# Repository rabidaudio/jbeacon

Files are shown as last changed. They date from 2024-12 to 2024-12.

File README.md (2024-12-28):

# JBeacon

Bluetooth beacons and Android app to stop forgetting your friggin keys.

- [Android App](/app)
- [PCB](/jbeacon)
- [Case model](https://cad.onshape.com/documents/ece1ed75d93c6672117b46a9/w/23cbe3629f57f254decfda38/e/c40ef07a7db79b811c868a6b)

## Licenses

Source Code is [MIT](LICENSE).

Hardware designs are [CC By 4.0](https://creativecommons.org/licenses/by/4.0/)

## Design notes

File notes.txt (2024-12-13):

MVP:
Show device - in range? approx distance?
Send notif when not in range
Send notif if bt disabled

optimize battery life

strech - app:
multiple devices
track location, record last known location
send notif when battery low

strech - hw:
buzzer: buzz when disconnected
buzz when commanded
acel/gyro motion detection to reduce advertising

https://cdn.sparkfun.com/assets/3/d/5/5/1/IN100-Datasheet.pdf

https://learn.sparkfun.com/tutorials/sparkfun-nanobeacon-board---in100-hookup-guide

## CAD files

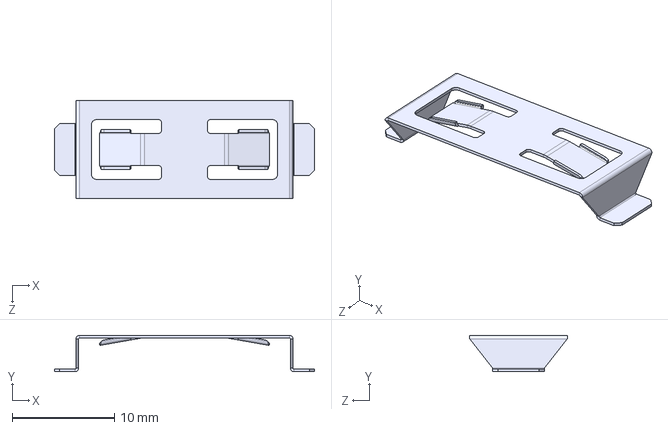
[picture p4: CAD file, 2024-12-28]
jbeacon/BC_2003_TR/BC-2003.step
25.4 x 3.56 x 9.53 mm

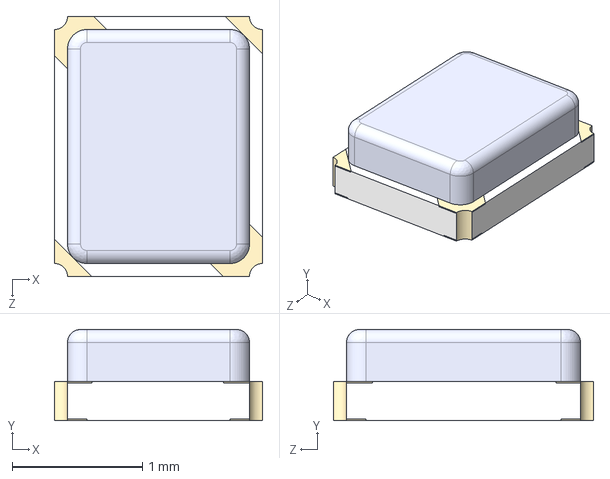
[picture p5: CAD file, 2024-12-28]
jbeacon/XRCGB26M000F2P00R0/XRCGB26M000F2P00R0.step
1.60 x 0.7 x 2.00 mm

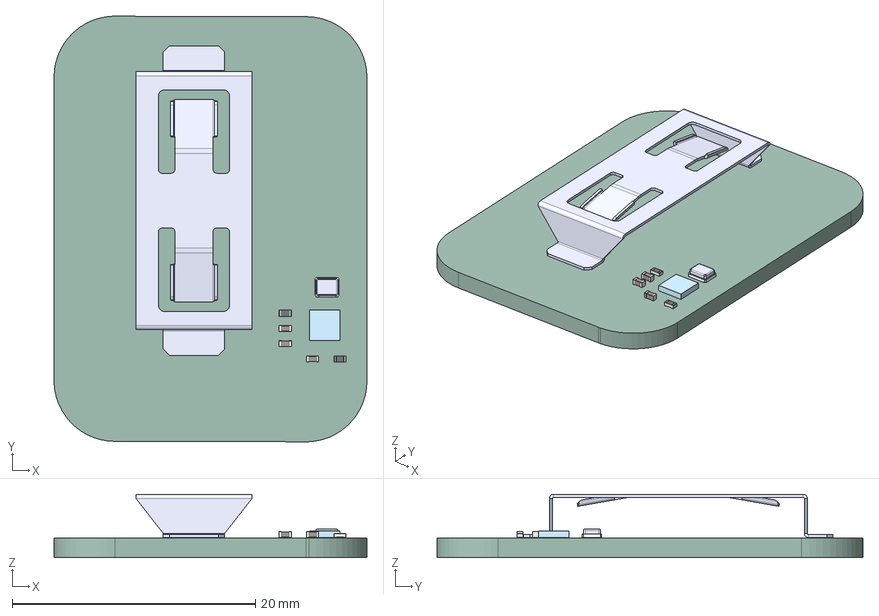
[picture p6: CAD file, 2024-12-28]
jbeacon/jbeacon.step
25.7 x 35.0 x 5.21 mm
C_0402_1005Metric x 3
XRCGB27M000F2P00R0
BC-2003
R_0402_1005Metric x 2
QFN8
jbeacon_PCB

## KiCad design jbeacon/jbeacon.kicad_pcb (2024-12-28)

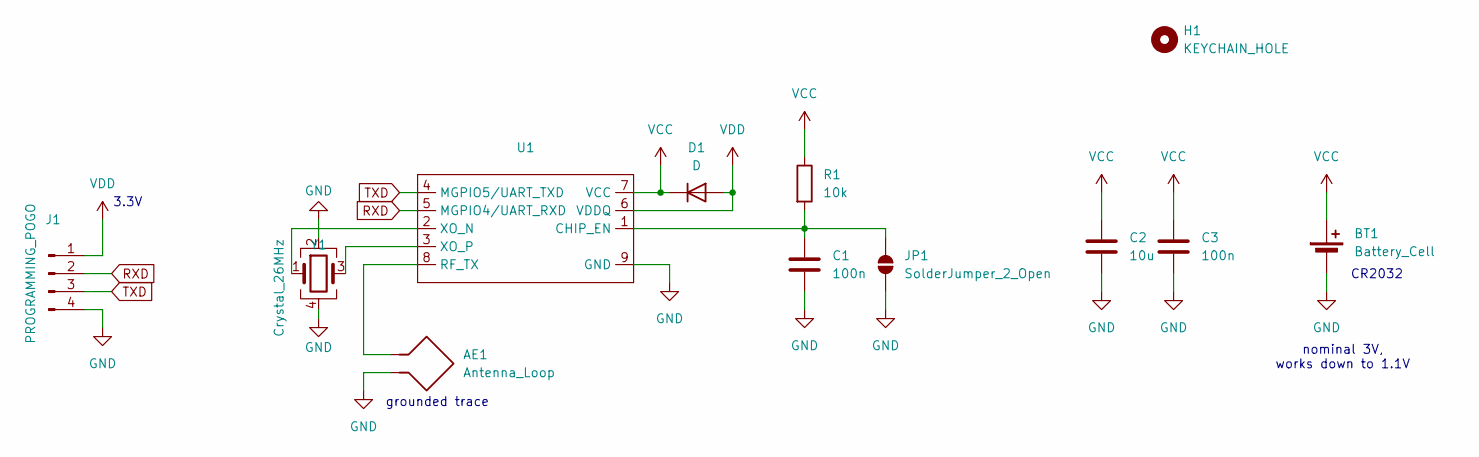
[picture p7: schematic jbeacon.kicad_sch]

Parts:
AE1: Antenna_Loop; rf_2.4ghz_pcb_antenna
BT1: Battery_Cell; BAT_BC-2003; Digikey_PN BC-2003-TR-CT-ND
C1, C3: 100n; C_0402_1005Metric; Digikey_PN 1276-1002-1-ND
C2: 10u; C_0402_1005Metric; Digikey_PN 1276-1451-1-ND
D1: D; D_0402_1005Metric; Digikey_PN 1N4148WL2-TPMSCT-ND
H1: KEYCHAIN_HOLE; MountingHole_3mm
J1: PROGRAMMING_POGO; pogo_4
JP1: SolderJumper_2_Open; SolderJumper-2_P1.3mm_Open_Pad1.0x1.5mm
R1: 10k; R_0402_1005Metric; Digikey_PN 311-10KJRCT-ND
U1: QFN-8_EP_2.5x2.5_Pitch0.5mm; Digikey_PN 3890-IN100-D1-R-YC1ICT-ND
Y1: Crystal_26MHz; OSC_XRCGB26M000F2P00R0; Digikey_PN 490-9764-1-ND

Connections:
GND: AE1.2, BT1.2 (-), C1.2, C2.2, C3.2, J1.4, JP1.1 (A), U1.9 (GND), Y1.2, Y1.4
unnamed: C1.1, JP1.2 (B), R1.2, U1.1 (CHIP_EN)
unnamed: AE1.1, U1.8 (RF_TX)
unnamed: U1.2 (XO_N), Y1.1
unnamed: U1.3 (XO_P), Y1.3
RXD: J1.2, U1.5 (MGPIO4/UART_RXD)
TXD: J1.3, U1.4 (MGPIO5/UART_TXD)
VCC: BT1.1 (+), C2.1, C3.1, D1.1 (K), R1.1, U1.7 (VCC)
VDD: D1.2 (A), J1.1, U1.6 (VDDQ)

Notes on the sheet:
3.3V
grounded trace
CR2032
nominal 3V, works down to 1.1V

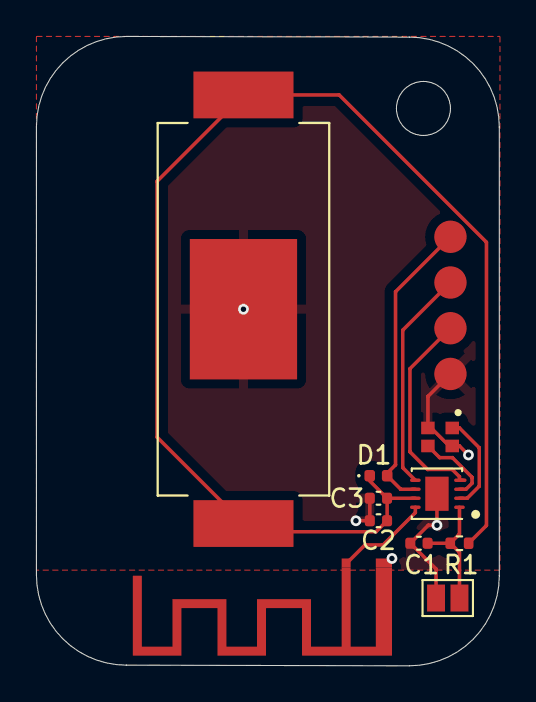
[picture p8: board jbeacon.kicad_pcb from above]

Board: 2 copper layers, 25.7 x 35.0 mm, 12 parts (0 on the bottom side), 9 nets.

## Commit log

2024-12-18 scanning for devices
2024-12-24 testing companion device
2024-12-28 Revert "testing companion device"
    This reverts commit 5826334c8fa2e39294f15a098563b7c059f815e0.
2024-12-28 recover pcb
    [jbeacon.kicad_pcb, jbeacon.kicad_sch]
2024-12-28 more cleanup
    [jbeacon.kicad_pcb]
2024-12-28 case CAD
    [BC-2003.step, QFN8.step, XRCGB26M000F2P00R0.step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]
